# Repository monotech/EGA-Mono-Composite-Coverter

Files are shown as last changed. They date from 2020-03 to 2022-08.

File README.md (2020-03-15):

Based on Hugo Holden's "FITTING AN EGA CARD TO AN IBM 5155" from 2016.

This plugs onto an EGA card's feature connector, such as the IBM EGA card.

It adds a crystal clear monochrome composite output in two places, untainted by the colour subcarrier.

* One internal 4-pin header, meant for the IBM 5155's internal amber CRT, which takes a standard composite video input.

* And one at the rear of the EGA card, on one of the usually unconnected RCA jacks.

  * The rear RCA jack output only applies to cards that have this RCA jack connected to the feature connector (P1 on the IBM EGA card: the top RCA jack).

You must set the card to CGA-compatible mode. If the card tries to output EGA-Hi-Res modes, the composite output will be unsupported by most monitors.

Simplified the schematic to reduce BoM and board size.

There is no longer provision for expanding the schematic to add colour-composite.

BoM:

|Designation|Part|
|---|---|
|U1, U2|74HCT86|
|Q1|2N3904|
|C1|4.7 to 10μF|
|C2|100nF|
|P1|2x16 2.54mm male pin header|
|P2|1x4 2.54mm male right-angle pin header|
|R1|75Ω|
|R2, R3|20Ω|
|R4|360Ω|
|R5|110Ω|
|R6|680Ω|
|R7|470Ω|
|R8|2kΩ|
|R9|4.3kΩ|
|R10|1kΩ|

* All parts are through-hole.
* U1 and U2 can be replaced by 74, 74LS, 74S, 74F, 74ACT.
* U2 can be replaced with a 74HCT32 - it will work the same.
* Q1 can be replaced with most general purpose NPN transistors - beware of pinout.
* Resistor tolerances can be 5% or less.
* R2 is only needed for the internal 4-pin header output, intended for IBM 5155.
* R3 is only needed for the rear RCA-jack output (P1 on IBM EGA card).

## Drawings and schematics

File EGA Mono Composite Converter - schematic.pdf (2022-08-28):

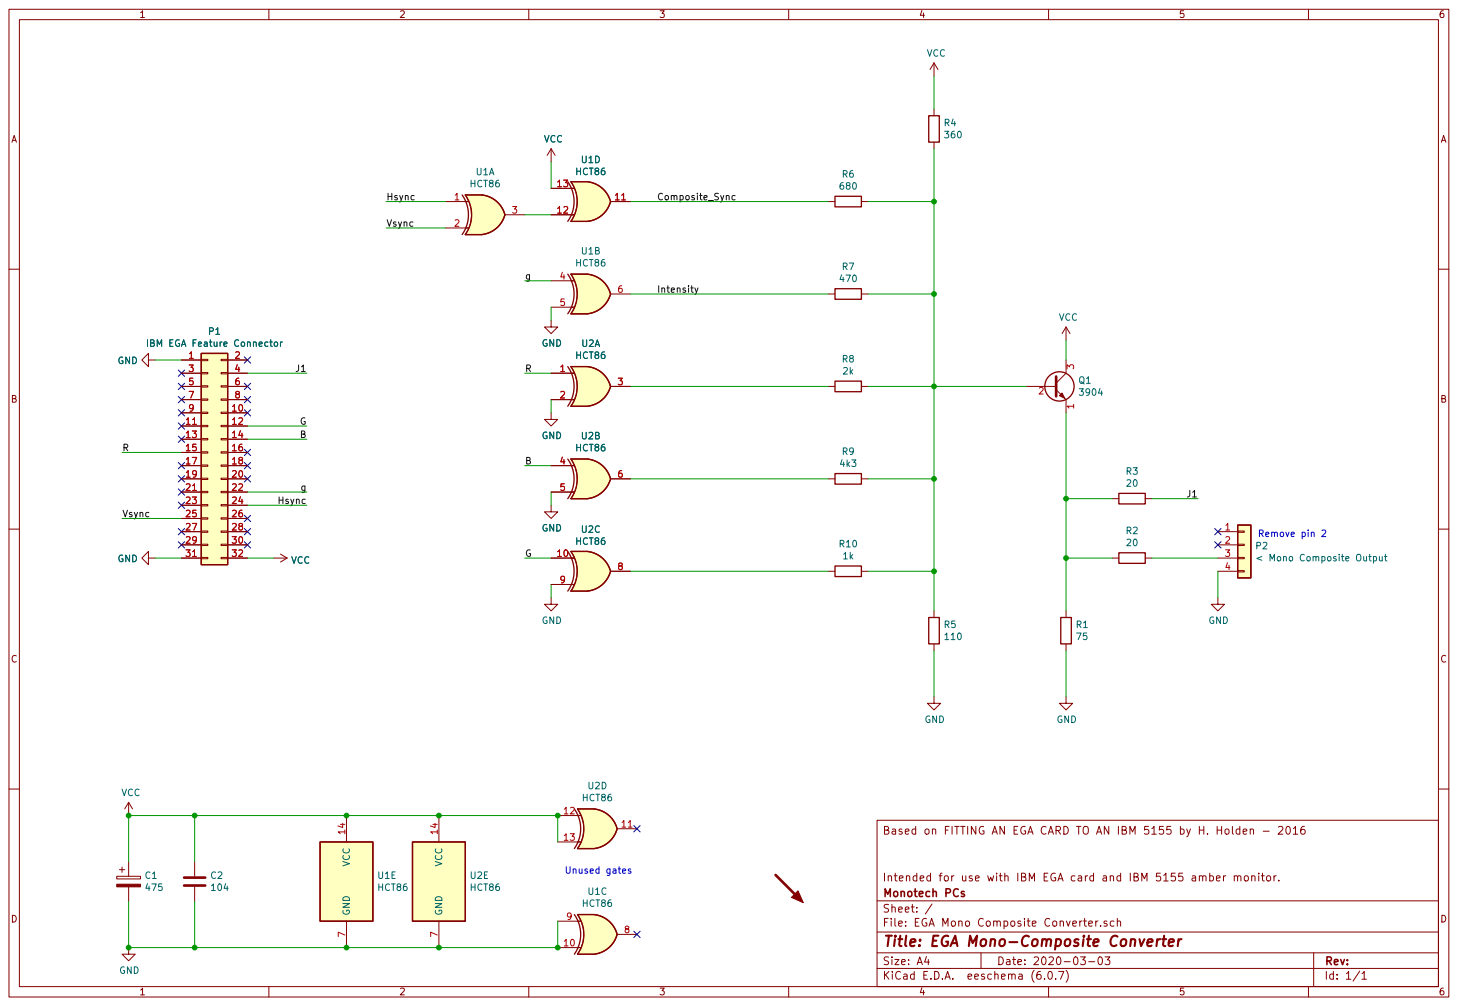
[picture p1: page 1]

IBM EGA Feature Connector GND
9 GND

IBM EGA Feature Connector 1

Intended for use with IBM EGA card and IBM 5155 amber monitor. Based on FITTING AN EGA CARD TO AN IBM 5155 by H. Holden - 2016 R1

File: EGA Mono Composite Converter.sch Sheet: / Monotech PCs

Id: 1/1 Title: EGA Mono-Composite Converter

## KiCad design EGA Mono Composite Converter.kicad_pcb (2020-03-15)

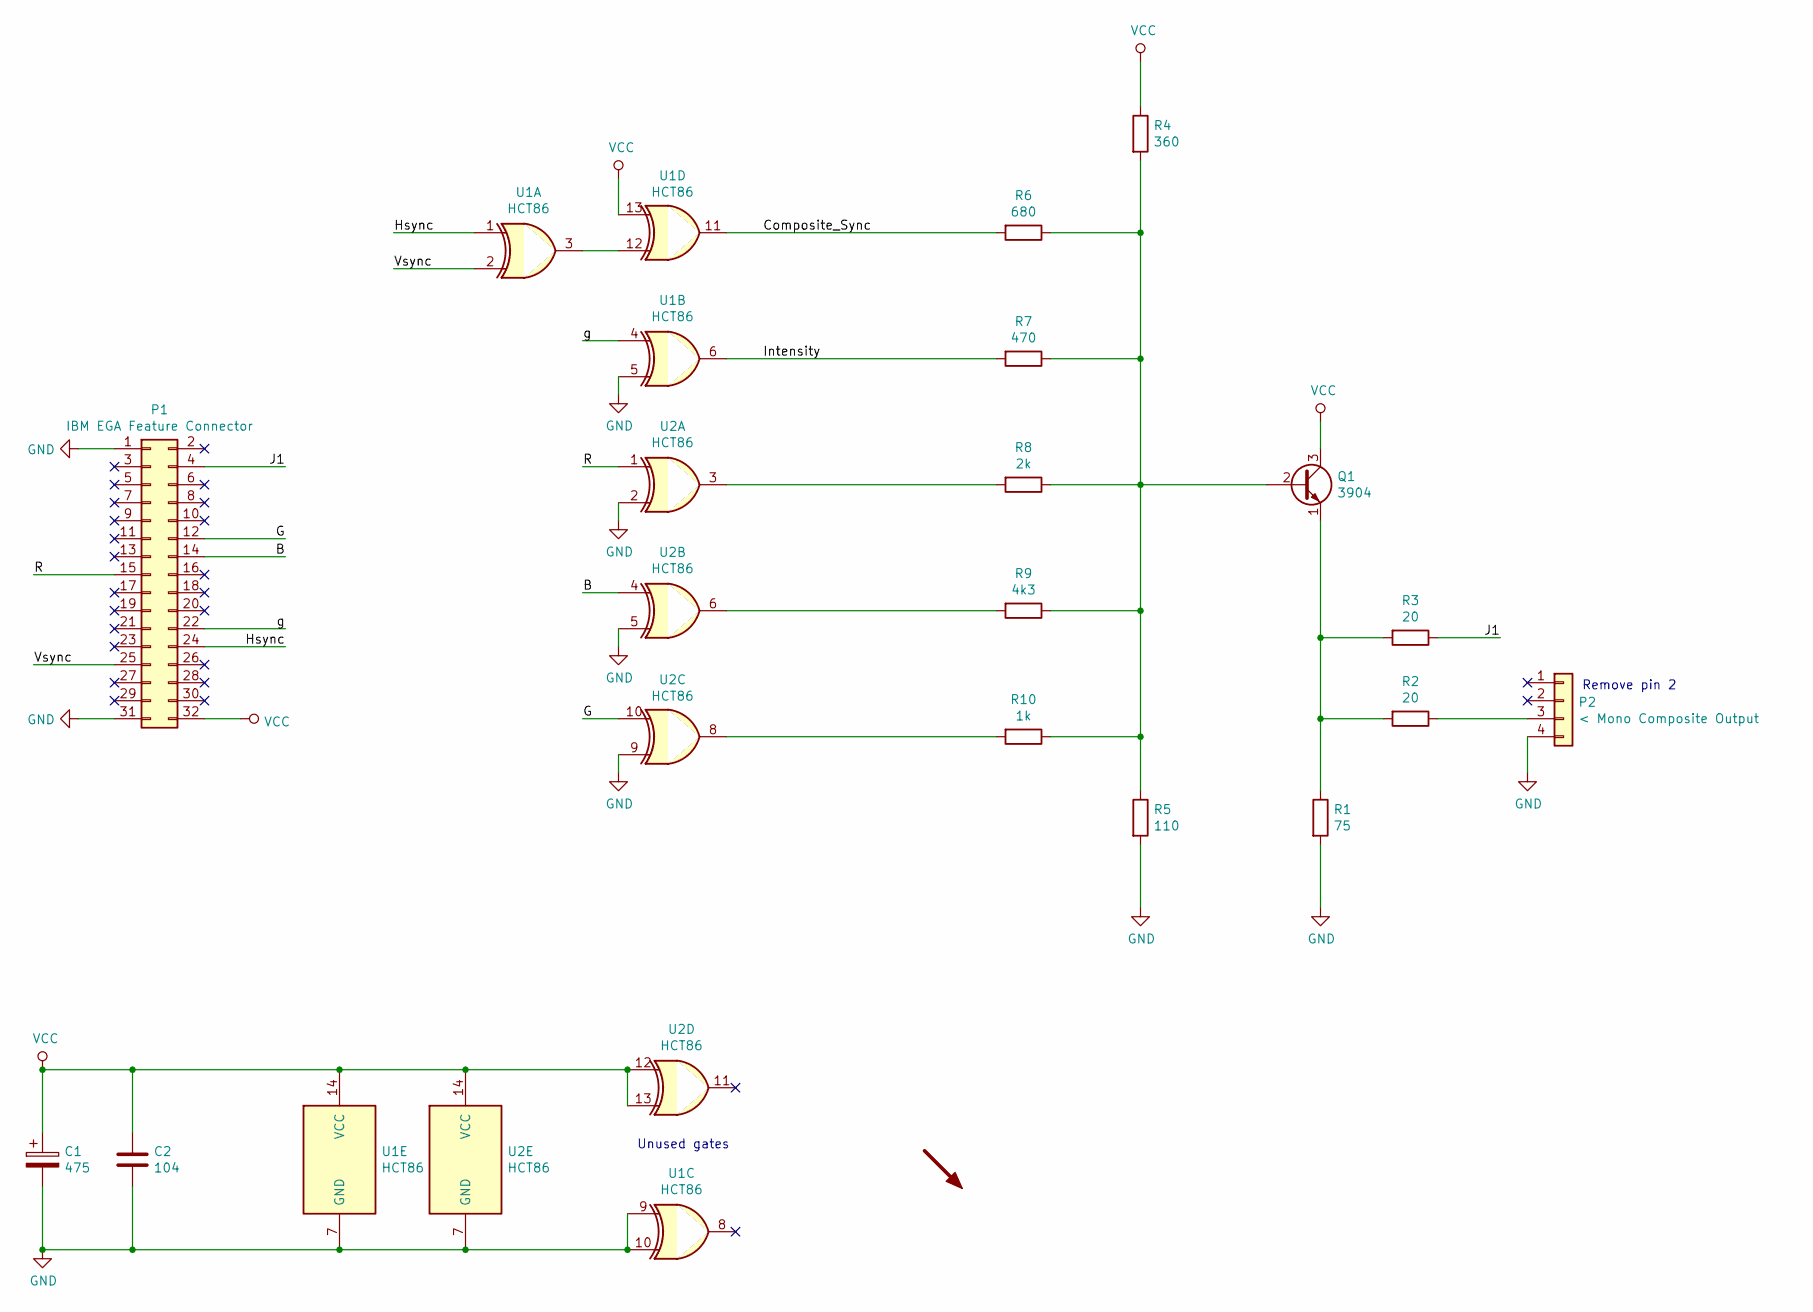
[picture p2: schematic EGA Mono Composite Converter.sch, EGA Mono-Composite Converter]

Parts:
C1: 475; C_Disc_D4.3mm_W1.9mm_P5.00mm
C2: 104; C_Axial_L3.8mm_D2.6mm_P7.50mm_Horizontal
LOGO1: SYM_Arrow45_Large; Monotech Logo 12mm
P1: IBM EGA Feature Connector; PinSocket_2x16_P2.54mm_Vertical
P2: < Mono Composite Output; PinHeader_1x04_P2.54mm_Horizontal
Q1: 3904; TO-92_Inline_Wide
R1: 75; R_Axial_DIN0207_L6.3mm_D2.5mm_P10.16mm_Horizontal
R2, R3: 20; R_Axial_DIN0207_L6.3mm_D2.5mm_P10.16mm_Horizontal
R4: 360; R_Axial_DIN0207_L6.3mm_D2.5mm_P10.16mm_Horizontal
R5: 110; R_Axial_DIN0207_L6.3mm_D2.5mm_P10.16mm_Horizontal
R6: 680; R_Axial_DIN0207_L6.3mm_D2.5mm_P10.16mm_Horizontal
R7: 470; R_Axial_DIN0207_L6.3mm_D2.5mm_P10.16mm_Horizontal
R8: 2k; R_Axial_DIN0207_L6.3mm_D2.5mm_P10.16mm_Horizontal
R9: 4k3; R_Axial_DIN0207_L6.3mm_D2.5mm_P10.16mm_Horizontal
R10: 1k; R_Axial_DIN0207_L6.3mm_D2.5mm_P10.16mm_Horizontal
U1, U2: HCT86; DIP-14_W7.62mm

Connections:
/B: P1.14, U2.4
/Composite_Sync: R6.2, U1.11
/G: P1.12, U2.10
/Hsync: P1.24, U1.1
/Intensity: R7.2, U1.6
/J1: P1.4, R3.1
/R: P1.15, U2.1
/Vsync: P1.25, U1.2
/g: P1.22, U1.4
GND: C1.2, C2.2, P1.1, P1.31, P2.4, R1.2, R5.2, U1.5, U1.7 (GND), U1.9, U1.10, U2.2, U2.5, U2.7 (GND), U2.9
unnamed: P2.3, R2.1
unnamed: Q1.1 (E), R1.1, R2.2, R3.2
unnamed: Q1.2 (B), R4.2, R5.1, R6.1, R7.1, R8.1, R9.1, R10.1
unnamed: R8.2, U2.3
unnamed: R9.2, U2.6
unnamed: R10.2, U2.8
unnamed: U1.3, U1.12
VCC: C1.1, C2.1, P1.32, Q1.3 (C), R4.1, U1.13, U1.14 (VCC), U2.12, U2.13, U2.14 (VCC)

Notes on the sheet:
Remove pin 2
Unused gates

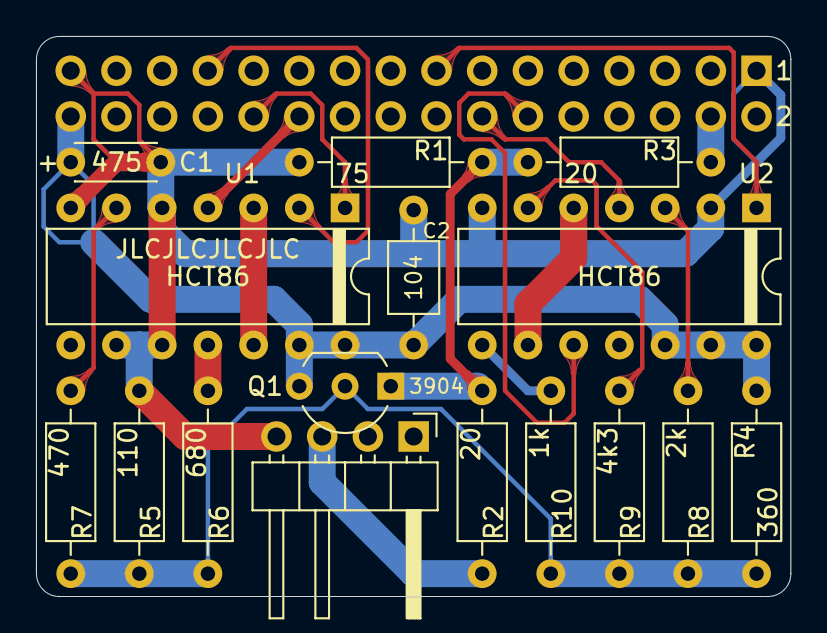
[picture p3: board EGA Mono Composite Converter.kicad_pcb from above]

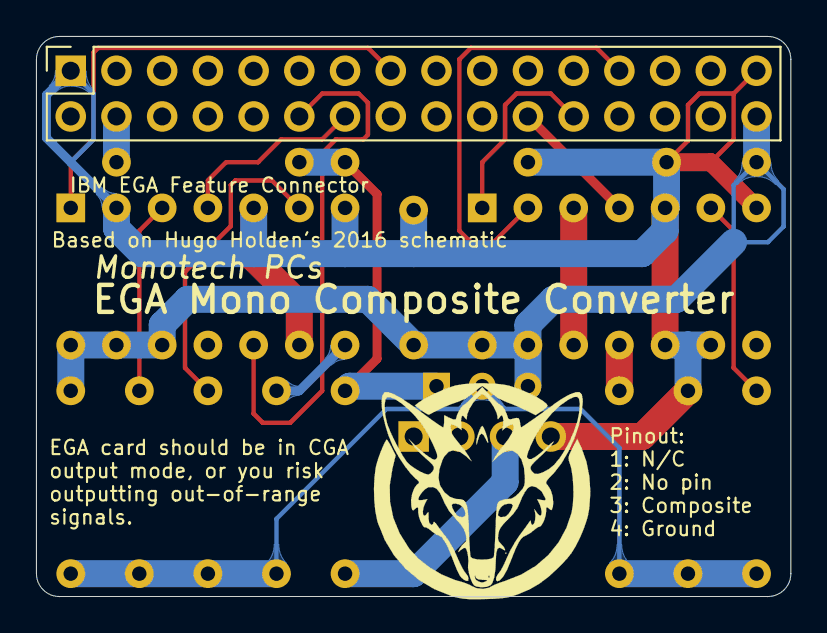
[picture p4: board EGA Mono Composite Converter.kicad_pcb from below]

Board: 2 copper layers, 41.9 x 31.1 mm, 18 parts (2 on the bottom side), 18 nets.
